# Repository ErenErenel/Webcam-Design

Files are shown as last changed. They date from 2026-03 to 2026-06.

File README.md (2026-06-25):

# Custom Embedded Webcam (SAM4S8B + OV2640 + ESP32)

A custom webcam system that captures JPEG images on a SAM4S8B microcontroller and
streams them to a browser over Wi-Fi via an ESP32 module. This repository contains
both the **PCB hardware design** and the **microcontroller firmware**.

Developed for **EE 326: Electronic System Design 1** at Northwestern University.

## System Overview

```
 OV2640 camera ──(parallel + I²C)──► SAM4S8B MCU ──(UART + SPI)──► ESP32 Wi-Fi ──► Browser
```

- The **OV2640** captures JPEG frames at 320×240, clocked into the MCU over an
  8-bit parallel interface using the SAM4S Peripheral DMA Controller (PDC).
  Camera registers are configured over I²C (TWI) at 400 kHz.
- The **SAM4S8B** (Cortex-M4) initializes the camera, detects JPEG frame length,
  and pushes image data to the ESP32 over SPI.
- The **ESP32-WROOM-32E** runs Wi-Fi provisioning, hosts a websocket server, and
  serves the streamed images to connected web clients. The MCU controls it through
  UART commands and monitors network/client status over GPIO.

## Repository Structure

```
Webcam-Design/
├── Hardware/      KiCad PCB design (schematic, layout, design rules)
│   ├── Ereno2.kicad_sch     Schematic
│   ├── Ereno2.kicad_pcb     Board layout
│   ├── Ereno2.kicad_pro     KiCad project
│   └── Ereno2.kicad_dru     Custom design rules
└── Firmware/      Atmel Studio (ASF) firmware for the SAM4S8B
    └── ErenFirmware/
        └── ErenFirmware/src/
            ├── main.c                  Boot, peripheral init, stream loop
            ├── camera.c / camera.h     OV2640 capture (PDC, JPEG framing)
            ├── ov2640.c / ov2640.h     OV2640 register driver + register tables
            ├── wifi.c / wifi.h         ESP32 UART command + SPI image transfer
            ├── timer_interface.c/.h    Timer/counter setup
            └── config/                 Board, clock, and UART configuration
```

## Firmware Flow

1. **Init** — system clock, watchdog disable, I/O ports, timer, USART, SPI, camera.
2. **ESP32 setup** — hard-reset the ESP32, then assign its GPIO roles
   (comm, network status, client status, provisioning, indicator LEDs) and SPI baud
   rate via UART commands.
3. **Connect** — wait for the ESP32 to join a network, handling provisioning requests
   from the on-board setup button; retry with `test`/reset until the link reports `SUCCESS`.
4. **Stream** — while a network and at least one client are connected, capture a frame
   and transfer it to the ESP32 for web display.

## Building the Firmware

The firmware targets the **ATSAM4S8B** and is built with **Microchip (Atmel) Studio 7**
using the Advanced Software Framework (ASF).

1. Open `Firmware/ErenFirmware/ErenFirmware.atsln` in Microchip Studio.
2. Build (`F7`) — output is generated in `Debug/` (ignored by git).
3. Flash to the board using a SAM-compatible programmer/debugger.

## Hardware

Open `Hardware/Ereno2.kicad_pro` in **KiCad 7+** to view or edit the schematic and
board layout. Key components: SAM4S8B MCU, OV2640 camera module, and an
ESP32-WROOM-32E-N4 Wi-Fi module.

## License

Released under the [MIT License](LICENSE).

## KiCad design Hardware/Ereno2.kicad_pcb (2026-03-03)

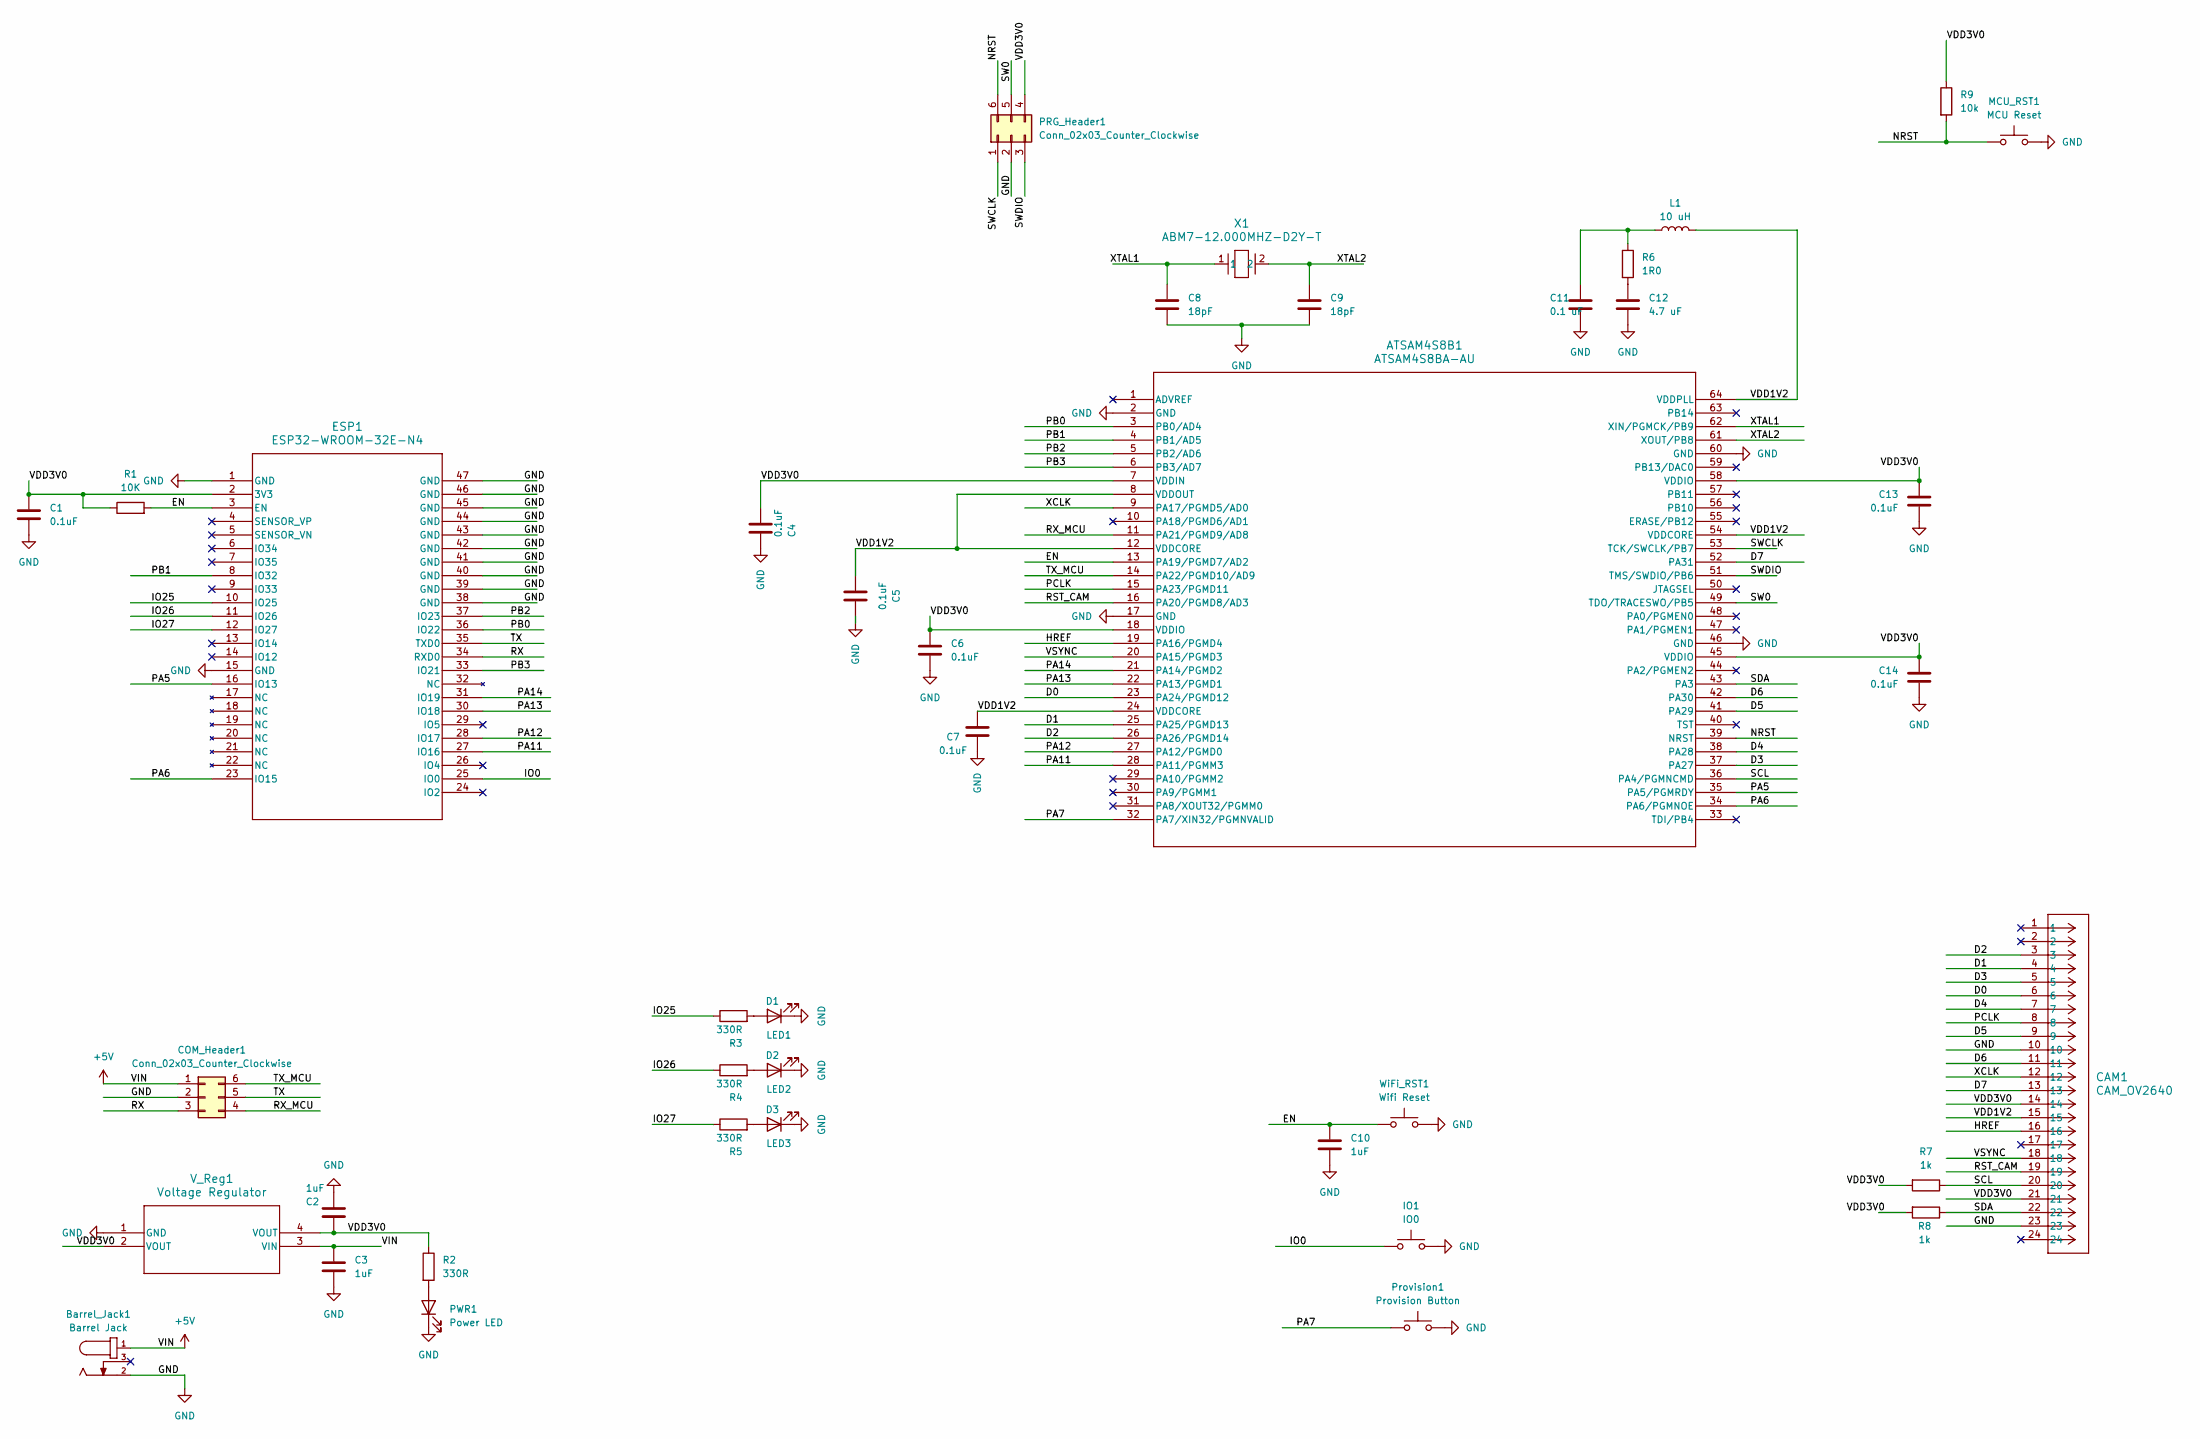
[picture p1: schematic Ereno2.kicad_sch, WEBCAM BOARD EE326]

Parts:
ATSAM4S8B1: ATSAM4S8BA-AU; LQFP64-2_ATM
Barrel_Jack1: Barrel Jack; 694106106102; DigiKey_Part_Number 732-5929-1-ND
C1, C4, C5, C6, C7, C13, C14: 0.1uF; C_0805_2012Metric
C2, C3, C10: 1uF; C_0805_2012Metric
C8, C9: 18pF; C_0805_2012Metric
C11: 0.1 uF; C_0805_2012Metric
C12: 4.7 uF; C_0805_2012Metric
CAM1: CAM_OV2640; CAM_CONN
COM_Header1: Conn_02x03_Counter_Clockwise; PinHeader_2x03_P2.54mm_Vertical
D1: LED1; LED_0201_0603Metric
D2: LED2; LED_0201_0603Metric
D3: LED3; LED_0201_0603Metric
ESP1: ESP32-WROOM-32E-N4; ESP32­WROOM­32E_EXP
IO1: IO0; pushbutton (1)
L1: 10 uH; L_0805_2012Metric
MCU_RST1: MCU Reset; pushbutton (1)
PRG_Header1: Conn_02x03_Counter_Clockwise; PinHeader_2x03_P2.54mm_Vertical
PWR1: Power LED; LED_0201_0603Metric_Pad0.64x0.40mm_HandSolder
Provision1: Provision Button; pushbutton (1)
R1: 10K; R_0805_2012Metric
R2, R3, R4, R5: 330R; R_0805_2012Metric
R6: 1R0; R_0805_2012Metric
R7, R8: 1k; R_0805_2012Metric
R9: 10k; R_0805_2012Metric
V_Reg1: Voltage Regulator; SOT223_STM
WiFi_RST1: Wifi Reset; pushbutton (1)
X1: ABM7-12.000MHZ-D2Y-T; XTAL_ABM7_ABR

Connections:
/D0: ATSAM4S8B1.23 (PA24/PGMD12), CAM1.6
/D1: ATSAM4S8B1.25 (PA25/PGMD13), CAM1.4
/D2: ATSAM4S8B1.26 (PA26/PGMD14), CAM1.3
/D3: ATSAM4S8B1.37 (PA27), CAM1.5
/D4: ATSAM4S8B1.38 (PA28), CAM1.7
/D5: ATSAM4S8B1.41 (PA29), CAM1.9
/D6: ATSAM4S8B1.42 (PA30), CAM1.11
/D7: ATSAM4S8B1.52 (PA31), CAM1.13
/EN: ATSAM4S8B1.13 (PA19/PGMD7/AD2), C10.1, ESP1.3 (EN), R1.2, WiFi_RST1.1
/HREF: ATSAM4S8B1.19 (PA16/PGMD4), CAM1.16
/IO0: ESP1.25 (IO0), IO1.1; also elsewhere on the board
/IO25: ESP1.10 (IO25), R3.1
/IO26: ESP1.11 (IO26), R4.1
/IO27: ESP1.12 (IO27), R5.1
/NRST: ATSAM4S8B1.39 (NRST), MCU_RST1.1, PRG_Header1.6, R9.2
/PA5: ATSAM4S8B1.35 (PA5/PGMRDY), ESP1.16 (IO13)
/PA6: ATSAM4S8B1.34 (PA6/PGMNOE), ESP1.23 (IO15)
/PA7: ATSAM4S8B1.32 (PA7/XIN32/PGMNVALID), Provision1.1
/PA11: ATSAM4S8B1.28 (PA11/PGMM3), ESP1.27 (IO16)
/PA12: ATSAM4S8B1.27 (PA12/PGMD0), ESP1.28 (IO17)
/PA13: ATSAM4S8B1.22 (PA13/PGMD1), ESP1.30 (IO18)
/PA14: ATSAM4S8B1.21 (PA14/PGMD2), ESP1.31 (IO19)
/PB0: ATSAM4S8B1.3 (PB0/AD4), ESP1.36 (IO22)
/PB1: ATSAM4S8B1.4 (PB1/AD5), ESP1.8 (IO32)
/PB2: ATSAM4S8B1.5 (PB2/AD6), ESP1.37 (IO23)
/PB3: ATSAM4S8B1.6 (PB3/AD7), ESP1.33 (IO21)
/PCLK: ATSAM4S8B1.15 (PA23/PGMD11), CAM1.8
/RST_CAM: ATSAM4S8B1.16 (PA20/PGMD8/AD3), CAM1.19
/RX: COM_Header1.3, ESP1.34 (RXD0)
/RX_MCU: ATSAM4S8B1.11 (PA21/PGMD9/AD8), COM_Header1.4
/SCL: ATSAM4S8B1.36 (PA4/PGMNCMD), CAM1.20, R7.1
/SDA: ATSAM4S8B1.43 (PA3), CAM1.22, R8.1
/SW0: ATSAM4S8B1.49 (TDO/TRACESWO/PB5), PRG_Header1.5
/SWCLK: ATSAM4S8B1.53 (TCK/SWCLK/PB7), PRG_Header1.1
/SWDIO: ATSAM4S8B1.51 (TMS/SWDIO/PB6), PRG_Header1.3
/TX: COM_Header1.5, ESP1.35 (TXD0)
/TX_MCU: ATSAM4S8B1.14 (PA22/PGMD10/AD9), COM_Header1.6
/VDD1V2: ATSAM4S8B1.8 (VDDOUT), ATSAM4S8B1.12 (VDDCORE), ATSAM4S8B1.24 (VDDCORE), ATSAM4S8B1.54 (VDDCORE), ATSAM4S8B1.64 (VDDPLL), C5.1, C7.1, CAM1.15, L1.2
/VDD3V0: ATSAM4S8B1.7 (VDDIN), ATSAM4S8B1.18 (VDDIO), ATSAM4S8B1.45 (VDDIO), ATSAM4S8B1.58 (VDDIO), C1.1, C2.1, C4.1, C6.1, C13.1, C14.1, CAM1.14, CAM1.21, ESP1.2 (3V3), PRG_Header1.4, R1.1, R2.1, R7.2, R8.2, R9.1, V_Reg1.2 (VOUT), V_Reg1.4 (VOUT)
/VIN: Barrel_Jack1.1, Barrel_Jack1.A1, C3.1, COM_Header1.1, V_Reg1.3 (VIN)
/VSYNC: ATSAM4S8B1.20 (PA15/PGMD3), CAM1.18
/XCLK: ATSAM4S8B1.9 (PA17/PGMD5/AD0), CAM1.12
/XTAL1: ATSAM4S8B1.62 (XIN/PGMCK/PB9), C8.1, X1.1
/XTAL2: ATSAM4S8B1.61 (XOUT/PB8), C9.1, X1.2
GND: ATSAM4S8B1.2 (GND), ATSAM4S8B1.17 (GND), ATSAM4S8B1.46 (GND), ATSAM4S8B1.60 (GND), Barrel_Jack1.2, C1.2, C2.2, C3.2, C4.2, C5.2, C6.2, C7.2, C8.2, C9.2, C10.2, C11.2, C12.2, C13.2, C14.2, CAM1.10, CAM1.23, COM_Header1.2, D1.1 (K), D2.1 (K), D3.1 (K), ESP1.1 (GND), ESP1.15 (GND), ESP1.38 (GND), ESP1.39 (GND), ESP1.40 (GND), ESP1.41 (GND), ESP1.42 (GND), ESP1.43 (GND), ESP1.44 (GND), ESP1.45 (GND), ESP1.46 (GND), ESP1.47 (GND), IO1.2, MCU_RST1.2, PRG_Header1.2, PWR1.1 (K), Provision1.2, V_Reg1.1 (GND), WiFi_RST1.2; also elsewhere on the board
unnamed: C11.1, L1.1, R6.1
unnamed: C12.1, R6.2
unnamed: D1.2 (A), R3.2
unnamed: D2.2 (A), R4.2
unnamed: D3.2 (A), R5.2
unnamed: PWR1.2 (A), R2.2

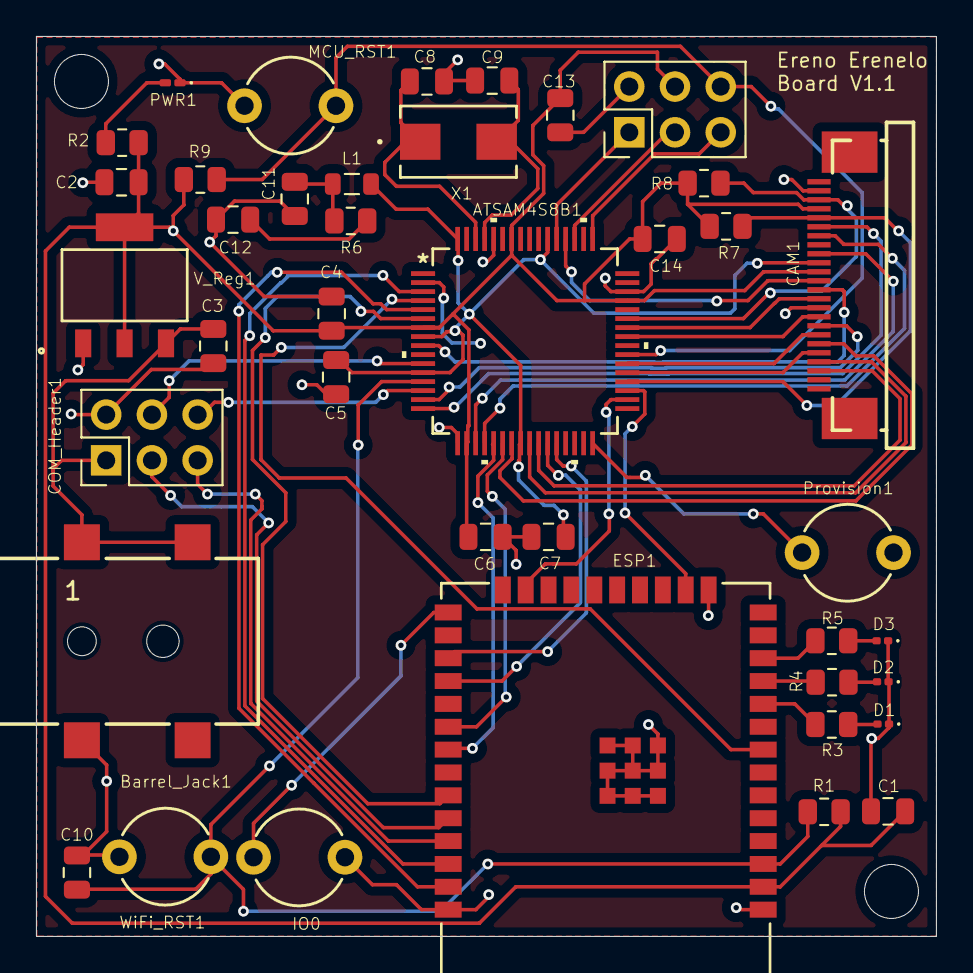
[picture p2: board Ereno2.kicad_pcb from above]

Board: 2 copper layers, 50.0 x 50.0 mm, 40 parts (0 on the bottom side), 51 nets.

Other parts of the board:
IO0: IO0; pushbutton (1)

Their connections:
/IO0: IO0.1; also elsewhere on the board
GND: IO0.2; also elsewhere on the board

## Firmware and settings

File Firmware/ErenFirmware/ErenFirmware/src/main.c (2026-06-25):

/*
 * main.c - SAM4S8B webcam streaming application
 *
 * EE 326: Electronic System Design 1 - Firmware Design
 * Created: 2/10/2026
 *  Author: Eren Erenel
 *
 * Initializes MCU peripherals, configures ESP32 WiFi module,
 * captures JPEG images from OV2640 camera, and streams them
 * to the ESP32 for web display.
 */

#include "wifi.h"
#include "camera.h"
#include "helpers/ov2640.h"
#include "timer_interface.h"
#include <asf.h>
#include "conf_board.h"
#include "conf_clock.h"


int main (void)
{
	/* System and peripheral initialization */
	sysclk_init();
	wdt_disable(WDT);
	ioport_init();
	board_init();
	configure_tc();
	configure_usart();
	configure_spi();
	configure_wifi_comm_pin();
	configure_wifi_provision_pin();
	 init_camera();
	 configure_camera();
	start_capture();

	/* Configure WiFi status pins as inputs */
	ioport_set_pin_dir(WIFI_NET_MASK,IOPORT_DIR_INPUT);
	ioport_set_pin_dir(WIFI_CLIENTS_STATUS_PIN_MASK,IOPORT_DIR_INPUT);
	ioport_set_pin_dir(WIFI_CLIENT_PIN_MASK,IOPORT_DIR_INPUT);
	ioport_set_pin_dir(WIFI_SETUP_BUTTON_MASK, IOPORT_DIR_INPUT);
	ioport_set_pin_mode(WIFI_SETUP_BUTTON_MASK,IOPORT_MODE_PULLUP);

	/* Hard reset ESP32: pull EN low, wait, then release */
	ioport_set_pin_dir(WIFI_RESET_MASK, IOPORT_DIR_OUTPUT);
	ioport_set_pin_mode(WIFI_RESET_MASK, IOPORT_MODE_PULLUP);
	ioport_set_pin_level(WIFI_RESET_MASK,false);
	delay_ms(500);
	ioport_set_pin_level(WIFI_RESET_MASK,true);
	delay_ms(500);


	/* Configure ESP32 GPIO assignments via UART commands */
	char* buff[100];
	sprintf (buff, "set comm_gpio %d",ESP_COMM_GPIO);
	delay_ms(10);
	write_wifi_command(buff,2);
	sprintf (buff, "set net_gpio %d", ESP_NET_GPIO);
	delay_ms(10);
	write_wifi_command(buff,2);
	sprintf (buff, "set clients_gpio %d", ESP_CLIENTS_STATUS_GPIO);
	delay_ms(10);
	write_wifi_command(buff,2);
	sprintf (buff, "set client_gpio %d", ESP_CLIENT_GPIO);
	delay_ms(10);
	write_wifi_command(buff,2);

	/* Configure ESP32 indicator LEDs (ESP-only, no MCU connection) */
	sprintf (buff, "set wlan_gpio %d", ESP_WLAN_LED);
	write_wifi_command(buff,2);
	sprintf (buff, "set websocket_gpio %d", ESP_WEBSOCKET_LED);
	write_wifi_command(buff,2);
	sprintf (buff, "set ap_gpio %d", ESP_AP_LED);
	write_wifi_command(buff,2);

	/* Set SPI baud rate on ESP32 */
	sprintf(buff, "set spi_baud %d", SPI_BAUDRATE);
	write_wifi_command(buff,2);

	reading_wifi_flag = false;
	provisioning_flag = false;

	/* Wait for ESP32 to connect to network; handle provisioning requests */
	while (!ioport_get_pin_level(WIFI_NET_MASK))	{

		if (provisioning_flag) {
			write_wifi_command("provision",1);
			provisioning_flag = false;
			write_wifi_command("get mac",1);
		}
	}

	/* Send "test" command, reset ESP32 on failure until "SUCCESS" received */
	while (!reading_wifi_flag)	{

		ioport_set_pin_level(WIFI_RESET_MASK,false);
		delay_ms(100);
		ioport_set_pin_level(WIFI_RESET_MASK,true);
		delay_ms(5000);

		write_wifi_command("test",10);
		delay_s(8);

	}

	/* Main loop: stream images when network + clients are available */
	while (1)	{
		if (provisioning_flag) {
			write_wifi_command("provision",1);
			provisioning_flag = false;
		}

		if (ioport_get_pin_level(WIFI_NET_MASK) && ioport_get_pin_level(WIFI_CLIENTS_STATUS_PIN_MASK))	{

			start_capture();
			if (len_success) {
				write_image_to_web();
			}
		}
	}

}

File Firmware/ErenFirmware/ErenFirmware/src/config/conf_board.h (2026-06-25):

/**
 * conf_board.h
 *
 * Board configuration for SAM4S + ESP32 webcam system (Katie/Janet wiring).
 */

#ifndef CONF_BOARD_H
#define CONF_BOARD_H

#include <asf.h>

/* --------------------------------------------------------------------------
 * ESP32 <-> SAM4S GPIO mapping (Katie/Janet connections)
 * -------------------------------------------------------------------------- */

/* ESP32 EN / RESET (MCU drives reset, active LOW)
 * SAM4S: PB0
 */
#define WIFI_RESET_PIO      PIOB
#define WIFI_RESET_PIO_ID   ID_PIOB
#define WIFI_RESET_PIN      PIO_PB0
#define WIFI_RESET_PIN_IDX  PIO_PB0_IDX
#define WIFI_RESET_ATTR     (PIO_OUTPUT_1 | PIO_DEFAULT)

/* ESP32 COMM (GPIO21 -> rising edge means “command complete”)
 * SAM4S: PA0
 * NOTE: wifi.h defines WIFI_COMM_* already; leaving here is optional.
 */

/* ESP32 NET (GPIO22 -> network connected)
 * SAM4S: PA1
 */
#define WIFI_NET_PIO        PIOA
#define WIFI_NET_PIO_ID     ID_PIOA
#define WIFI_NET_PIN        PIO_PA1
#define WIFI_NET_PIN_IDX    PIO_PA1_IDX
#define WIFI_NET_ATTR       (PIO_INPUT | PIO_PULLUP)

#define BOARD_FREQ_SLCK_XTAL      32768
#define BOARD_FREQ_SLCK_BYPASS    32768
#define BOARD_FREQ_MAINCK_XTAL    12000000
#define BOARD_FREQ_MAINCK_BYPASS  12000000
/* ESP32 WS/CLIENTS (GPIO23 -> websocket clients connected)
 * SAM4S: PA2
 */
#define WIFI_WS_PIO         PIOA
#define WIFI_WS_PIO_ID      ID_PIOA
#define WIFI_WS_PIN         PIO_PA2
#define WIFI_WS_PIN_IDX     PIO_PA2_IDX
#define WIFI_WS_ATTR        (PIO_INPUT | PIO_PULLUP)

/* Provision button is PB3 (handled in wifi.h as WIFI_PROVISION_*).
 * If you want it also defined here, you can, but not required.
 */

#endif /* CONF_BOARD_H */

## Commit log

2026-03-03 pcb files
    [Ereno2.kicad_pcb]
2026-06-25 Add .gitignore and commit updated KiCad schematic and project files
    [Ereno2.kicad_sch]
2026-06-25 Restructure into Hardware/ and Firmware/; merge in SAM4S webcam firmware
    - Rename "Webcam PCB" -> Hardware/ for a clear modular layout
    - Add Firmware/ containing the SAM4S8B firmware (camera, OV2640, Wi-Fi)
    previously in the standalone EE326_Firmware repo
    - Untrack KiCad autosave file; ignore firmware build artifacts
    [Ereno2.kicad_pcb, Ereno2.kicad_sch]
2026-06-25 Write detailed README covering system, structure, firmware flow, and build
